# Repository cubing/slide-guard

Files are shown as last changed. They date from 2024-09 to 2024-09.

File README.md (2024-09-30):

# Slide guard for speedcubing timers

An inexpensive slide guard for speedcubing timers. The current prototype is compatible with SpeedStacks G5 mats and timers.

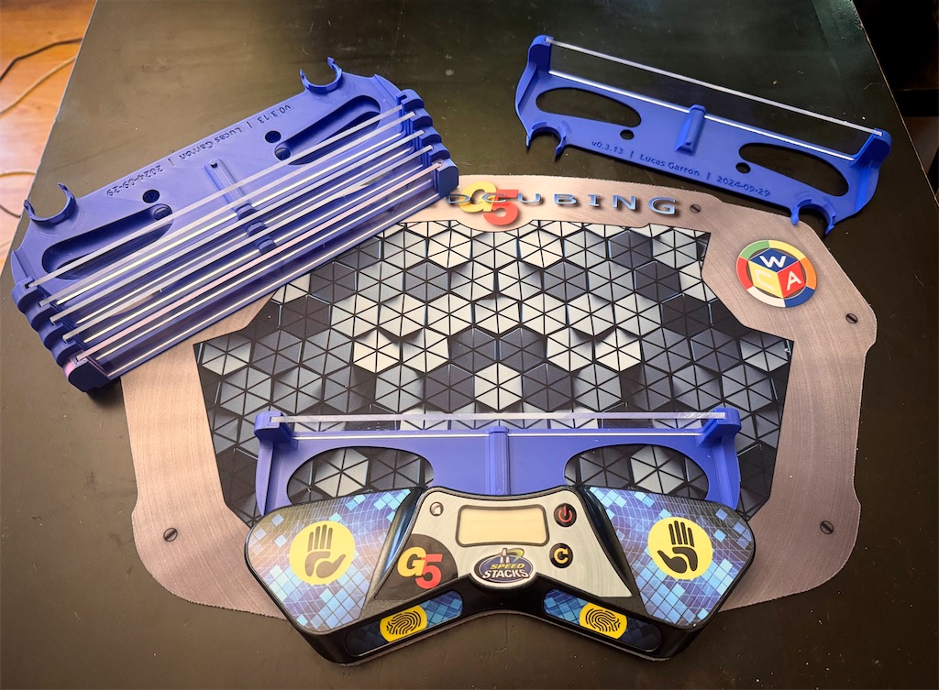
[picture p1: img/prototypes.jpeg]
Prototypes on a table: a stack, an assembled slide guard, and one attached to a G5 mat and timer

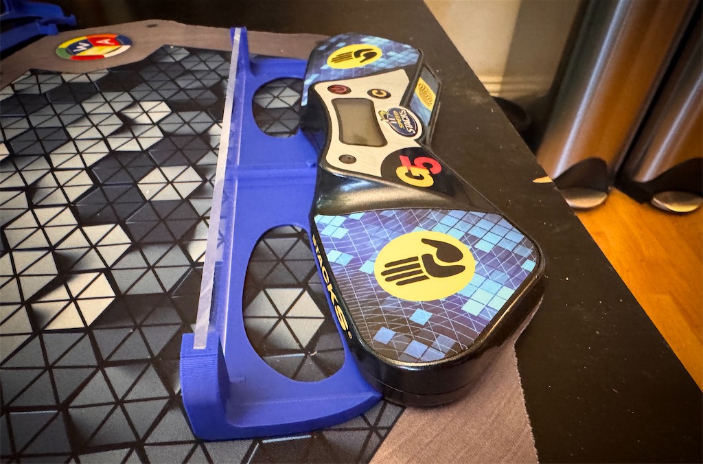
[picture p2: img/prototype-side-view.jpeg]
Side view of the prototype, showing how a piece of acrylic is helf in front of the timer.


The full prototype consists of:

| Item | Size | Material cost |
| - | - | - |
| Clear acrylic | 9in × 1in × ⅛in | ≤ $1 |
| Mounting bracket | 250mm × 77.1mm × 27.1mm | ≤ $1 |

The acrylic height can also vary in height (i.e. the 1in dimension can be shorter or longer).

I personally get my acrylic from [TAP Plastics](https://tapplastics.com/).

The design for the mounting bracket is in this repo. It can be 3D-printed in a consumer 3D printer, and is also designed so that it can be injection moulded in a single shot.

## Future improvements

- Improve 3D printing time (currently 45 minutes).
- Add stacking pins to the side ledges.
- Adjust the acrylic position (or replace with two separate angled pieces) to make it easier to place the puzzle on the mat at the end of the attempt.

## Files

This repo includes:

- Source files: SVG and [OpenSCAD](https://openscad.org/).
- STL: a rendered export from OpenSCAD. Units are millimeters.
- `.3mf` files: files from [Bambu Studio](https://bambulab.com/en/download/studio) ready to print.

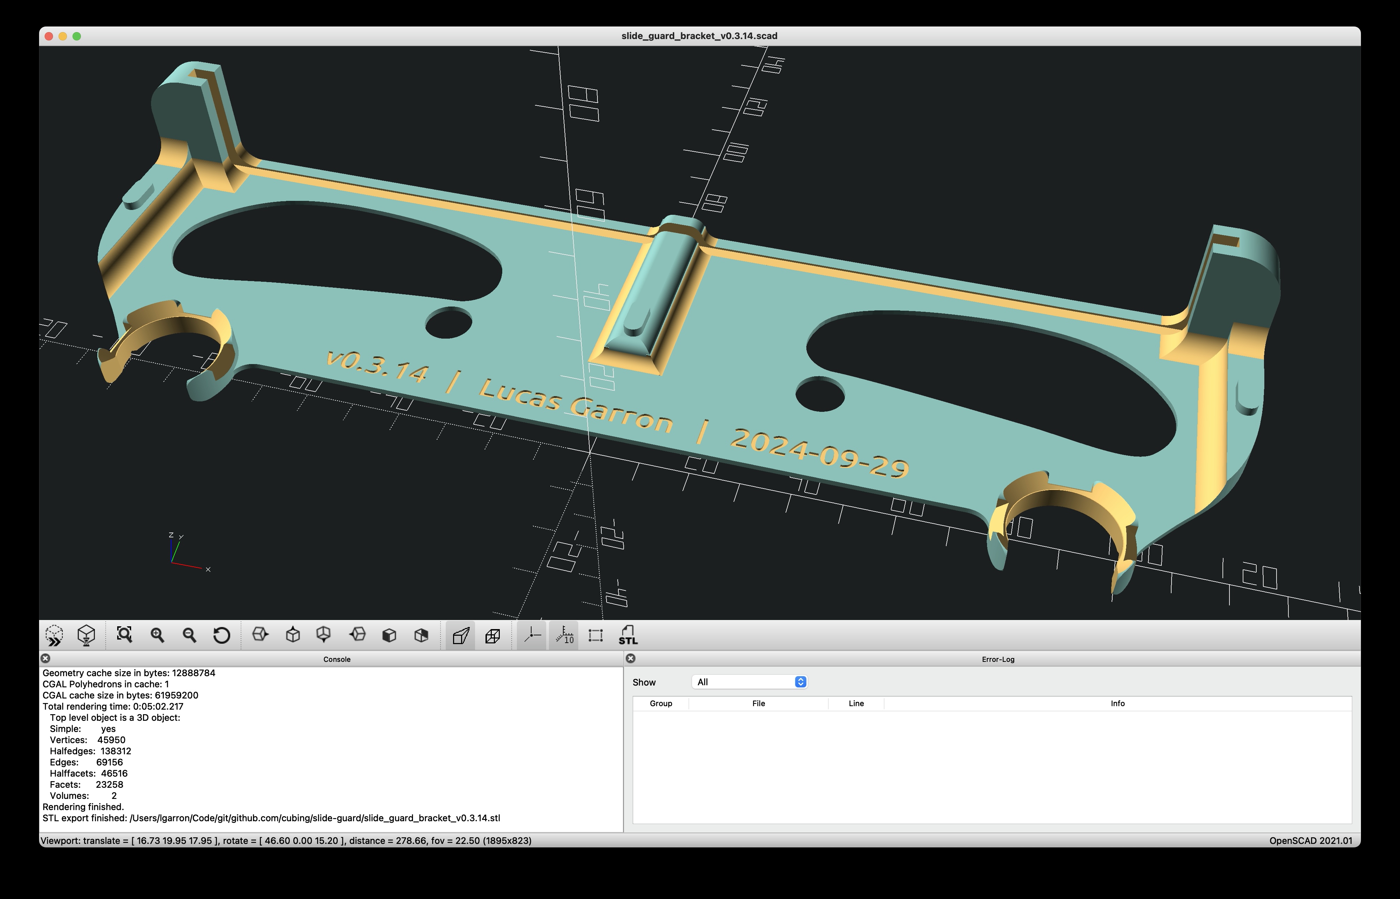
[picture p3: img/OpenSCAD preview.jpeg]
Preview of the bracket in OpenSCAD.
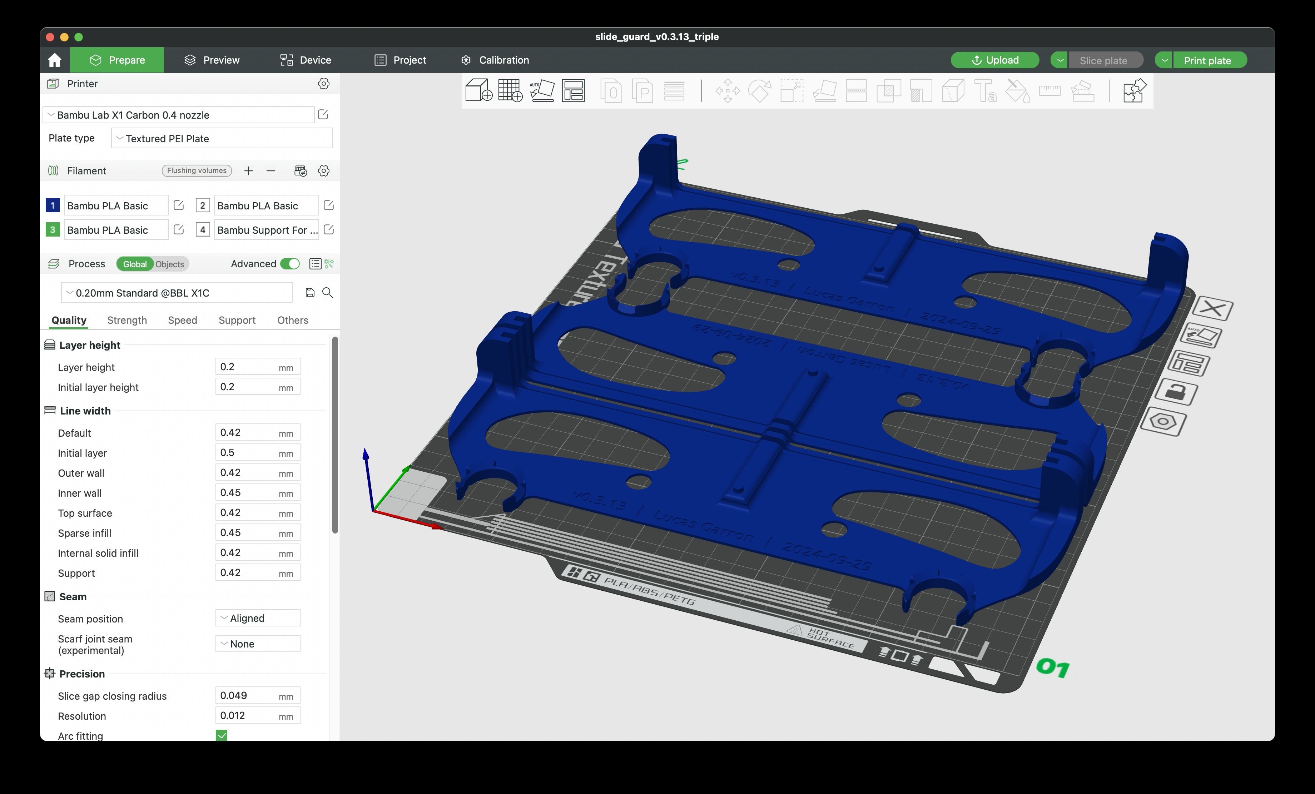
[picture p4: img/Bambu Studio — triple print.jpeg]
Preview of 3 copies of the bracket in Bambu Studeio.


## Video demo

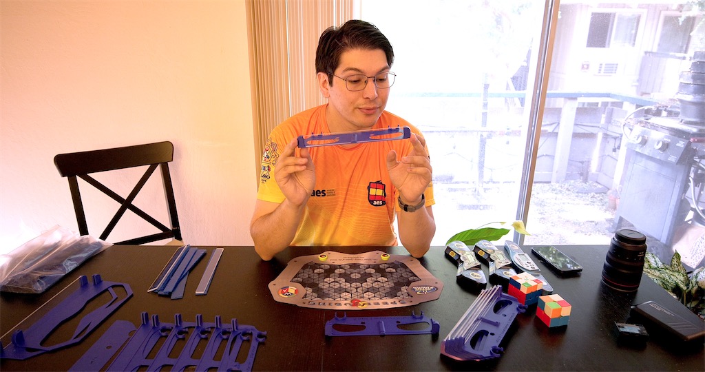
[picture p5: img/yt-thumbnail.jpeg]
Video frame of Lucas Garron holding up a prototype, surrounded by several iterations of prototypes on a table.
<a href="https://www.youtube.com/watch?v=npT4VVcEYHo">https://www.youtube.com/watch?v=npT4VVcEYHo<br></a>

## License

This work is licensed under the Creative Commons Attribution-ShareAlike 4.0 license ([CC-By-SA 4.0](https://creativecommons.org/licenses/by-sa/4.0/deed.en)).

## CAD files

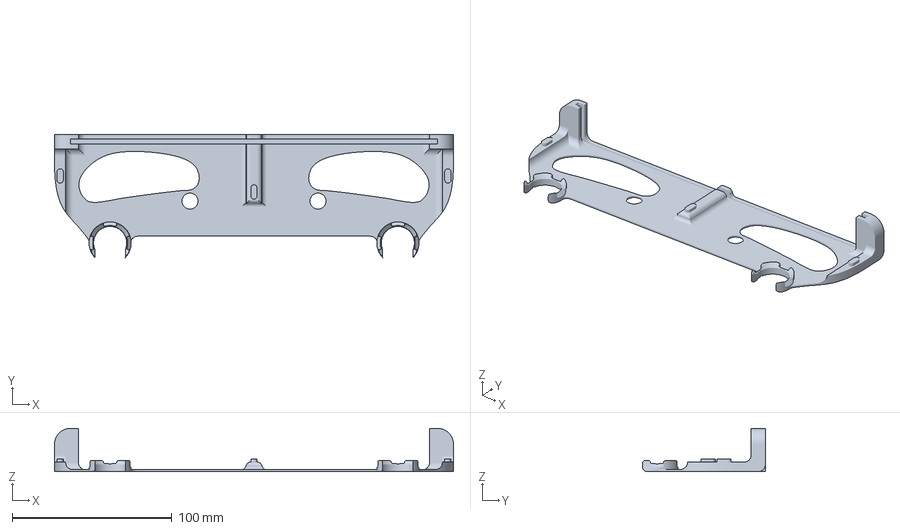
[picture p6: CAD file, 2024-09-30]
slide_guard_bracket_v0.3.14.3mf
250.0 x 77.1 x 27.1 mm

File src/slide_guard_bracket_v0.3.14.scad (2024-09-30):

FILE_REVISION = "v0.3.14   |   Lucas Garron   |   2024-09-29";

LOW_FI_DEV = false; // Enable this for faster iteration in OpenSCAD
INCLUDE_FLOATING_TEXT = false; // Can be lowered into the engraving as a different print color.

$fn = LOW_FI_DEV ? 9 : 256;

/*

## v0.3.14

- Add stacking plugs to the ledges.
- Change stacking plugs to be longer and fix up dimensions.
- Add floating text that can be used to fill engraving with a different-colo filament.

## v0.3.13

- Increase holder height by 1mm.
- Move small holes (for timer feet) forward 1mm.
- Add antibevel to the insides of the holders.
- Add anti-bevel to the middle support.

## v0.3.12

- Change the middle support to a bar that goes all the way to the end.
- Resize the big holes in the hopes of reducing forward-rocking.
- Remove x-axis contact spacing from the front stackings bevel.
- Remove contact spacing from the middle support plug.

## v0.3.11

- Reduce size of big holes.
- Adjust the stacking offset z to prevent the top of the clamp stacking port from showing as a thin slot through the top
of the plate.
- Adjust plexiglass holder to line up the top better.
- Move middle support closer to the timer.

## v0.3.10

- Lower trunk height by 0.5mm.
- Add side ledges.
- Add stacking bevels.
- Decrease y depth by 5mm.
- Add middle support.

## v0.3.9

- Slightly adjust the plexiglass slot dimensions.
- Move clamps 1mm apart (yet once more).

## v0.3.8

- Move clamps 1mm apart (once more).
- Reduce plexiglass slot dimensions back.

## v0.3.7

- Add big holes in the baseplate for volume reduction.
- Increase holder anti-bevel size.
- Remove bottom holder bevel.
- Increase plexiglass slot width.

## v0.3.6

- Set base plate height to `timer_ground_clearance`.
- Add holders.
- Carve plexiglass slot.

## v0.3.5

- Add a base plate (test height only)

## v0.3.4

- Changed ground clearance from 1.5mm to 1.2mm
- Added pincer top bevel.
- Changed pincer bottom bevel from 2mm to 3mm.

*/

// All units are millimeters.

EPSILON = 0.1;
CONTACT_SPACING = 0.2;
SNUG_CONTACT_ANTISPACING = 0.2;
INCH = 25.4;

DEFAULT_BEVEL_RADIUS = 2;

/********************************/

module duplicate_to_mirror_x() {
    children();
    if (!LOW_FI_DEV) {
        mirror([1, 0, 0]) children();
    }
}

/********************************/

plate_width_x = 250;
plate_depth_y = 68; // does NOT include pincers

module plate(extrude_height_z)
{
    translate([ -plate_width_x / 2, 0, 0 ]) linear_extrude(extrude_height_z)
    {
        import(file = "slide_guard_bracket_v0.3.13_plate.svg", dpi = INCH);
    }
}

/********************************/

bevel_lip = 1;

module round_bevel_cylinder(radius, width)
{
       translate([ 0, radius, radius ]) rotate([ 0, 90, 0 ]) cylinder(h = width + EPSILON, r = radius, center = true);
    
}

module round_bevel_complement(radius, width)
{
    difference()
    {
        translate([ 0, radius / 2 - bevel_lip / 2, radius / 2 - bevel_lip / 2 ])
            cube([ width, radius + bevel_lip, radius + bevel_lip ], center = true);
        round_bevel_cylinder(radius, width);
    }
}

/********************************/

plug_trunk_height = 4.55;
plug_trunk_radius = 21.1 / 2;
plug_head_lower_slope_height = 2.5; // 2.5 minus a bit to account for the rounded outside

port_barrel_outer_radius = 26 / 2;
port_clip_width = 7.9;

pincer_flex = 2;

pincer_bottom_bevel_radius = 3;

module clamp_carver(z_rot)
{
    z = plug_trunk_height + 1;
    rotate([ 0, 0, z_rot ]) union()
    {
        translate([ port_barrel_outer_radius - z / 2, 0, z ]) rotate([ 0, 45, 0 ]) translate([ 0, 0, z / 2 ])
            cube([ 10, port_clip_width + 2 * CONTACT_SPACING - SNUG_CONTACT_ANTISPACING, z ], center = true);

        translate([ 0, port_clip_width / 2, plug_trunk_height + plug_head_lower_slope_height ]) mirror([ 0, 0, 1 ])
            round_bevel_complement(radius = DEFAULT_BEVEL_RADIUS * 0.9,
                                   width = port_barrel_outer_radius * 2 + EPSILON * 2);

        mirror([ 0, 1, 0 ]) translate([ 0, port_clip_width / 2, plug_trunk_height + plug_head_lower_slope_height ])
            mirror([ 0, 0, 1 ]) round_bevel_complement(radius = DEFAULT_BEVEL_RADIUS * 0.9,
                                                       width = port_barrel_outer_radius * 2 + EPSILON * 2);
    }
}

module clamp(radius_epsilon)
{
    h = plug_trunk_height + plug_head_lower_slope_height;
    difference()
    {
        union()
        {
            translate([ 0, 0, h / 2 ]) cylinder(
                h = h, r = (port_barrel_outer_radius + radius_epsilon) + SNUG_CONTACT_ANTISPACING, center = true);

            // translate([ 0, (port_barrel_outer_radius + radius_epsilon), timer_ground_clearance / 2 ]) cube(
            //     [ (port_barrel_outer_radius + radius_epsilon) * 2, (port_barrel_outer_radius + radius_epsilon) * 2,
            //     timer_ground_clearance ], center = true);
        }

        union()
        {
            translate([ 0, 0, plug_trunk_height + plug_head_lower_slope_height / 2 + EPSILON / 2 ])
                cylinder(h = plug_head_lower_slope_height + EPSILON,
                         r1 = (port_barrel_outer_radius + radius_epsilon) - plug_head_lower_slope_height,
                         r2 = (port_barrel_outer_radius + radius_epsilon) + EPSILON, center = true);

            translate([ 0, 0, h / 2 ])
                cylinder(h = h + EPSILON, r = (plug_trunk_radius - radius_epsilon) - CONTACT_SPACING, center = true);

            clamp_carver(0);
            clamp_carver(90);
            clamp_carver(180);
            clamp_carver(270);
            translate([ 0, -10, 0 ])
                cube([ (plug_trunk_radius - radius_epsilon) * 2 - pincer_flex, 20, 20 ], center = true);

            MAGIC_NUMBER_TO_AVOID_TRIG = -9.115;
            // Bottom pincer bevel
            translate([ 0, MAGIC_NUMBER_TO_AVOID_TRIG, 0 ])
                round_bevel_complement(radius = pincer_bottom_bevel_radius,
                                       width = (port_barrel_outer_radius + radius_epsilon) * 2 + EPSILON * 2);

            // Top pincer bevel
            translate([ 0, MAGIC_NUMBER_TO_AVOID_TRIG, plug_trunk_height + plug_head_lower_slope_height ])
                mirror([ 0, 0, 1 ])
                    round_bevel_complement(radius = DEFAULT_BEVEL_RADIUS,
                                           width = (port_barrel_outer_radius + radius_epsilon) * 2 + EPSILON * 2);
        }
    }
}

module clamps(radius_epsilon)
{
    interclamp_distance = 204 - 25.7 + 2;

    translate([ interclamp_distance / 2, 0, 0 ]) clamp(radius_epsilon);
    translate([ -interclamp_distance / 2, 0, 0 ]) clamp(radius_epsilon);

    main_width = 10 * INCH;
    length = 2 * INCH;
}

/********************************/

timer_ground_clearance = 1.2;

holder_width_x = 15;
holder_depth_y = 9;
holder_height_z = INCH + 1; // 1 to accommodate for imperfect plexiglass and plastic.
holder_bevel_radius = 10;
holder_front_antibevel_radius = plug_trunk_height;

plexiglass_carving_width_x = 9 * INCH + 1 + CONTACT_SPACING * 2;
plexiglass_carving_depth_y = INCH / 8 - SNUG_CONTACT_ANTISPACING / 2; // snug
plexiglass_carving_height_z = holder_height_z + EPSILON; // 0.5 to accommodate for imperfect plexiglass and plastic.

plexiglass_inset_z = 0.5;

stacking_offset_y = holder_depth_y;
stacking_offset_z = timer_ground_clearance + plug_trunk_height +
                    0.2; // 0.2 avoids the top of the clamp stacking receiver from showing through the top of the plate.

module middle_plexiglass()
{
    translate([
        0, plate_depth_y - holder_depth_y / 2, plexiglass_carving_height_z / 2 + timer_ground_clearance + EPSILON / 2 -
        plexiglass_inset_z
    ]) cube([ plexiglass_carving_width_x, plexiglass_carving_depth_y, plexiglass_carving_height_z + EPSILON ],
            center = true);
}

stacking_holder_bevel = 2;

module uncarved_holder()
{
    difference()
    {
        translate([ -plate_width_x / 2, plate_depth_y - holder_depth_y, timer_ground_clearance - plexiglass_inset_z ])
            cube([ holder_width_x, holder_depth_y, holder_height_z ]);

        translate([
            -plate_width_x / 2, plate_depth_y - holder_depth_y / 2, holder_height_z + timer_ground_clearance -
            plexiglass_inset_z
        ]) rotate([ 0, 0, -90 ]) mirror([ 0, 0, 1 ])
            round_bevel_complement(radius = holder_bevel_radius, width = holder_depth_y + EPSILON);
    }

    translate([ -plate_width_x / 2 + holder_width_x / 2, plate_depth_y - holder_depth_y, timer_ground_clearance ])
        mirror([ 0, 1, 0 ]) round_bevel_complement(radius = holder_front_antibevel_radius, width = holder_width_x);

difference() {
    translate([-plate_width_x / 2 + holder_width_x, plate_depth_y - holder_depth_y / 2 - holder_front_antibevel_radius / 2, timer_ground_clearance])
    rotate([0, 0, -90])
    round_bevel_complement(radius = holder_front_antibevel_radius, width = holder_depth_y + holder_front_antibevel_radius);
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
